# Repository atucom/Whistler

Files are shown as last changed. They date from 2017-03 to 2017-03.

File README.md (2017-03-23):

# Whistler
### What is it?
A small handheld device that precisely mimics the tone and volume of a HID RFID card readers
### Why?
Often times on Red Team engagements, you will gain access to a building via tailgating. Sometimes, if the employees are well trained, they will turn around and ask you to make sure you badge in if they don't see the movement and/or hear the characteristic beep of a card read.
### Design
The design of the latest version is a very simplistic circuit. I use an RC circuit to control the timing of a 555 timer which controls an NPN transistor hooked up to a Star Micronics TMB-05. The RC circuit controls the discharge of the capacitor for a precise amount of time. I'v measured the beep time on a number of readers and they all seem to be ~250ms. I've replicated the beep time fairly precisely as seen on my oscilloscope:
Scope Reading

### Bill of Materials:
For Revision E:
* 1x 2.2 Mega Ohm Resistor
* 1x 1.0 Kilo Ohm Resistor
* 2x 0.1uF Capacitor
* 1x TMB-05
* 1x 555 Timer
* 2x CR1220 Coin Cell Batteries
* 1x Pushbutton
* 2x CR1220 Coin Cell Holders
* 1x NPN Transistor

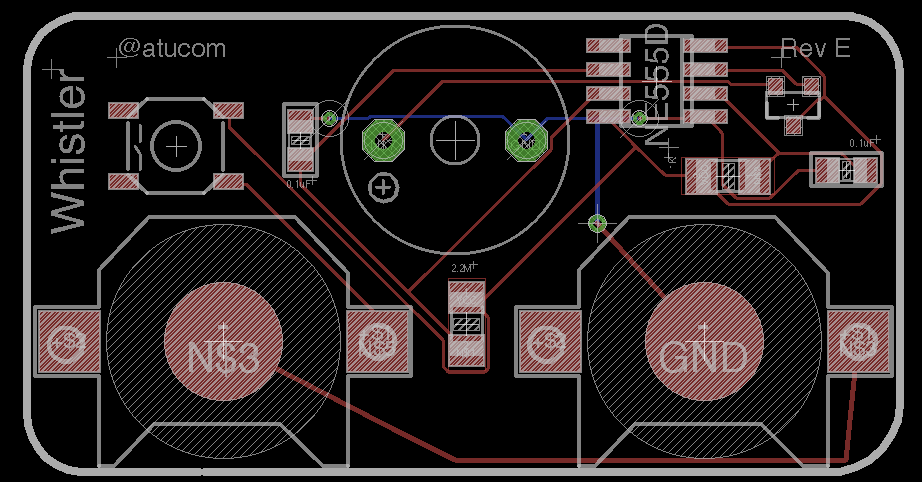
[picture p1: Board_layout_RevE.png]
Board Layout


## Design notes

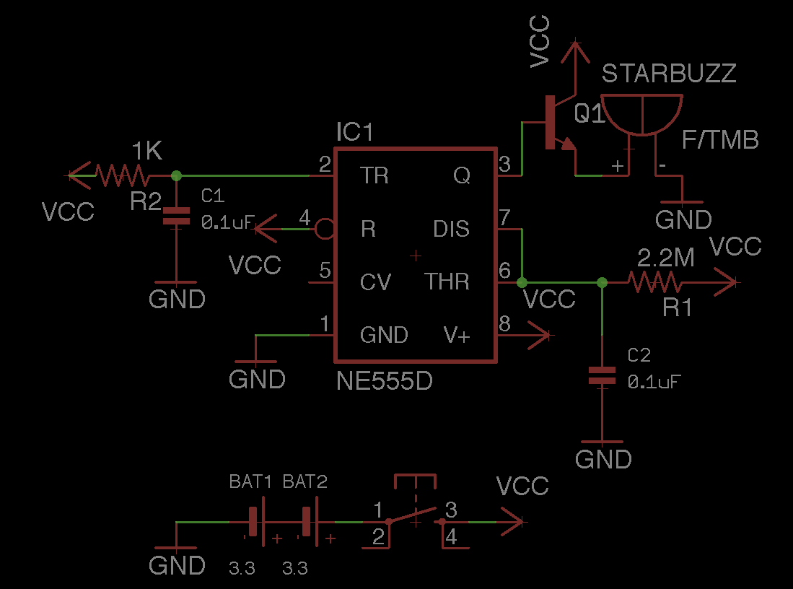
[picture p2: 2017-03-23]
Schematic_RevE.png

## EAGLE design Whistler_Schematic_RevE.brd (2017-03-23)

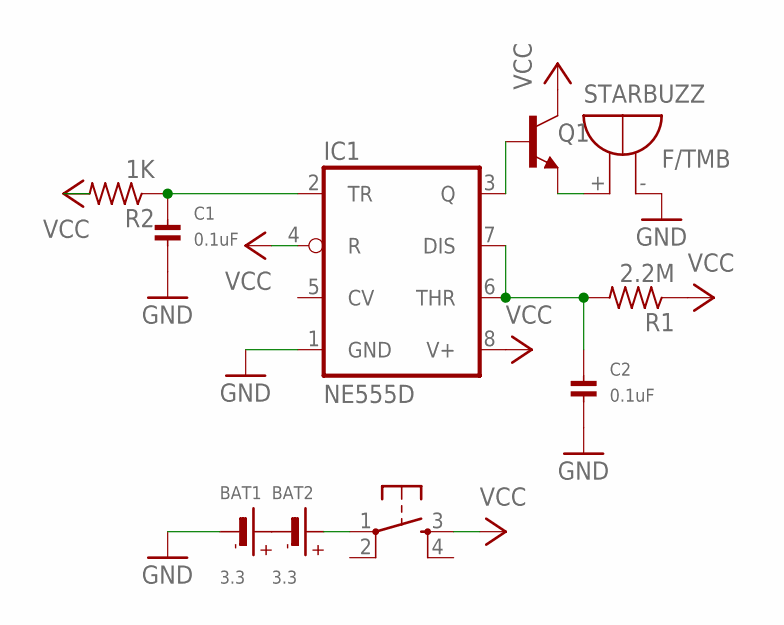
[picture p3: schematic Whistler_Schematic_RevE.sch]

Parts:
BAT1, BAT2: 3.3; CR1220
C1, C2: 0.1uF; _0805
IC1: NE555D; SO08
Q1: TRANS_NPN-MMBT2222AL; SOT23-3
R1: 2.2M; R1206
R2: 1K; R1206
S2: TAC_SWITCHSMD; TACTILE-SWITCH-SMD
STARBUZZ: F/TMB

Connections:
GND: BAT1.-, C1.2, C2.2, IC1.1 (GND), STARBUZZ.-
unnamed: C2.1, IC1.6 (THR), IC1.7 (DIS), R1.2
unnamed: C1.1, IC1.2 (TR), R2.1
unnamed: BAT1.+$1 (+), BAT2.-
unnamed: IC1.3 (Q), Q1.1 (B)
unnamed: BAT2.+$1 (+), S2.1
unnamed: Q1.2 (E), STARBUZZ.+
VCC: IC1.4 (R), IC1.8 (V+), Q1.3 (C), R1.1, R2.2, S2.3

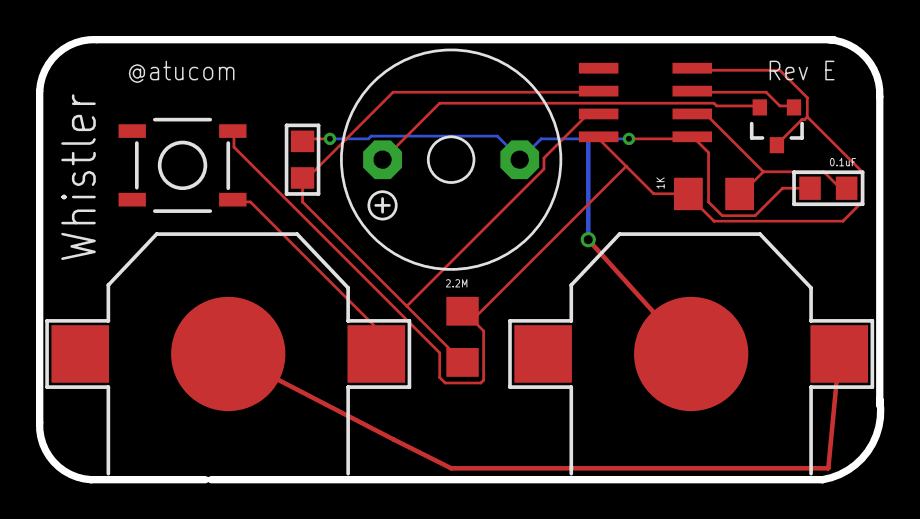
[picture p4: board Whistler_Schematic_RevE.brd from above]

Board: 2 copper layers, 46.7 x 24.4 mm, 10 parts (0 on the bottom side), 8 nets.

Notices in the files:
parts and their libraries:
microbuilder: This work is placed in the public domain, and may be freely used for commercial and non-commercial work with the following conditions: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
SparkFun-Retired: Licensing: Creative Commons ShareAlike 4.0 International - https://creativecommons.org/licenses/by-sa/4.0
